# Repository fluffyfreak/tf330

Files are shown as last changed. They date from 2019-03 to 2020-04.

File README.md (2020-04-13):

# tf330

TF330 source files. 

Published under GPL v2. 

TF330 is distributed with absolutely no warranty. If you make a mistake you could blow up your CD32. I take no responsibility for this. 

The TF330 is an 030 accelerator fixed at 50Mhz with 64Mb of SDRAM (128Mb possible), WIFI support (via ESP8266) and is intended to work with CF cards or IDE2SD card type devices. The IDE interface does not work with long cables. It is intended to be CHEAP Because thats pretty much all Amiga users care about. 

**Before you start building :- You can buy these from Supaduper & AlenPPC (AmiBay) completely built for less than it will cost you to buy the parts and the time it will take you if you bill your time at minimum wage.**

If you have poor soldering skills and feel the need to mock me for not using through hole technology please dont bother. I've heard it all before and I will just laugh at you. Through hole sucks. 

Also do not ask me to reroute the board to a different DRC so you can use your local boardhouse. I dont feel like spending 100 hours of my time to save you $10. The DRC on this board is 7-7-7 and any boardhouse that doesnt totally suck can do this. Also it 4 layer and dont ask if i can be made 2 layer. The answer is no. 

If you need help with this the best place to get it is the exxos forum https://www.exxoshost.co.uk/forum/ 

Please do not message me directly. Start a thread. 

I do my best to help people who ask polite questions in public but if you make your inadequecies my problem then you are on your own. 

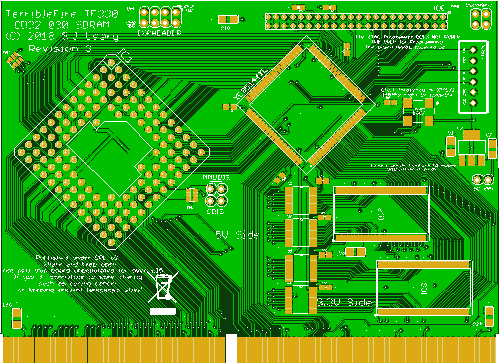
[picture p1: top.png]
Top of board


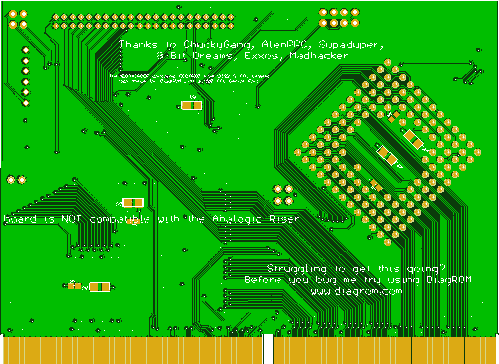
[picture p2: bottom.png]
Bottom of board


I dont care if you think my HDL is not pristine either. It works perfecly fine for what its intended to be. I lothe the wordy VHDL language.. it breaks the most basic principle of coding .. .DONT REPEAT YOURSELF. There is a full regression test suite in my development repo that I have chosen not to share.

The SDRAM Controller is derived from my Archie core and the clock controller code is designed to simulate a PLL with adjustable phase. 

This is not an exercise in German over engineering. Its properly engineered to do an exact task and nothing more. Its a simple repeatable board that works and there are about 500 of them built and working reliably.

I dont like forks because i dont like options. Options mean more testing and more testing = time. So if you fork you are on your own but if you fork and dont give credit I will make it my mission in life to punish you. I will summon the ancient retro spirits of evil like Jack Tramiel and have them haunt you for all time. You have been warned. 

I know this seems a bit hostile but really its just from hard experience of Amiga people. I give this out for free but there are people out there who will take the piss and try to rip off amiga users with clones baring their own name, others will get one of these off ebay for £15 and expect me to invest 100s of hours in helping them get it going. Yet others will try to be smart arses and tell me i've done X, Y or Z wrong and this will never work. If for any reason you decide this board does not measure up to whatever standard YOU think it should be... take a hike. I dont care. 

That said you are free to sell this on your webshop provided you give credit and do not vastly overprice it. However CE marking is your own issue not mine. 

On the other hand if you have an actual firmware bugfix send me a pull request with testing evidence. It will be appreciated greatly. 

For crashes please check that the crash doesnt happen in WinUAE for a CD32 with A1200 IDE and 64MB ZIII Ram before making a bug report. Most of the crashes we have seen over the years are repeatable in that environment. 

This version of the board is cloned from my private repository and is GPL. The version in my private repo is not GPL and anything derived from it is not subject to the GPL v2. It is highly likely that I will eventually release everything in my private repo. I just do so at a pace that keeps the freeloaders and price gougers from making much out of me.

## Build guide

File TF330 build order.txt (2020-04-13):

My order of the build is 

1.    CPLD
2.    Bus switch x4
3.    All 100nf caps x8
4.    SD ram  x2
5.    1K Resistor arrays x2
6.    Volt Reg
7.    10uf caps x3 (Top Board)
8.    22uf  caps x3  (Top board)
9.    Crystal Oscillator 
10.  1uf  x4 (Bottom board)
11.  10uf  x3 (Bottom Board)
12.  030 pga socket (Optional) or 030 CPU
13.  1k  thick film resistors x2 ( by IDE header)
14.  44 pin IDE header socket

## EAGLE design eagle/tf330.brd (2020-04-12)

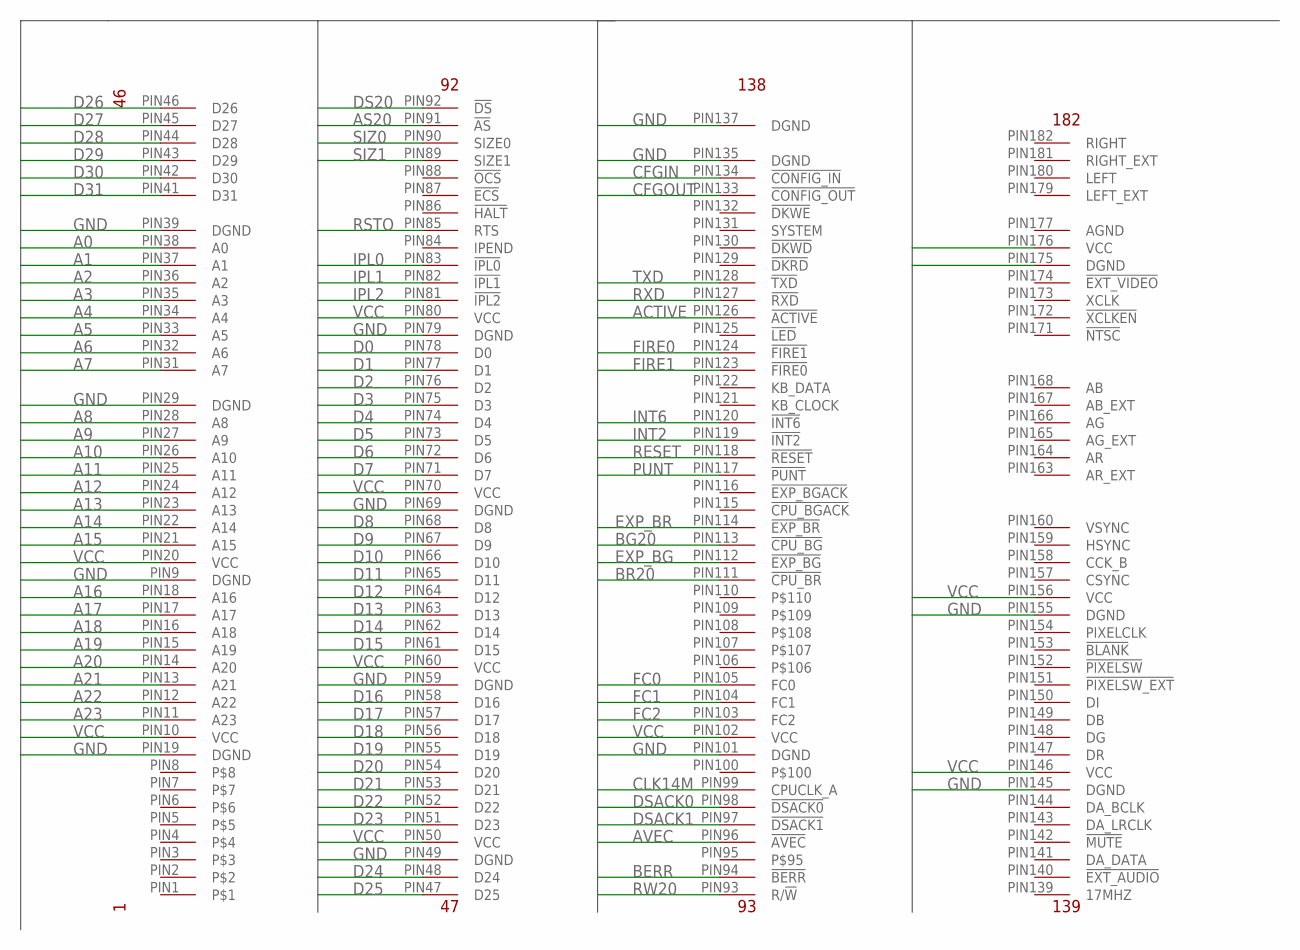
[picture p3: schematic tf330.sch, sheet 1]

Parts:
CONN1: MCA_CONN_182

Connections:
A0: CONN1.PIN38 (A0); also elsewhere on the board
A1: CONN1.PIN37 (A1); also elsewhere on the board
A2: CONN1.PIN36 (A2); also elsewhere on the board
A3: CONN1.PIN35 (A3); also elsewhere on the board
A4: CONN1.PIN34 (A4); also elsewhere on the board
A5: CONN1.PIN33 (A5); also elsewhere on the board
A6: CONN1.PIN32 (A6); also elsewhere on the board
A7: CONN1.PIN31 (A7); also elsewhere on the board
A8: CONN1.PIN28 (A8); also elsewhere on the board
A9: CONN1.PIN27 (A9); also elsewhere on the board
A10: CONN1.PIN26 (A10); also elsewhere on the board
A11: CONN1.PIN25 (A11); also elsewhere on the board
A12: CONN1.PIN24 (A12); also elsewhere on the board
A13: CONN1.PIN23 (A13); also elsewhere on the board
A14: CONN1.PIN22 (A14); also elsewhere on the board
A15: CONN1.PIN21 (A15); also elsewhere on the board
A16: CONN1.PIN18 (A16); also elsewhere on the board
A17: CONN1.PIN17 (A17); also elsewhere on the board
A18: CONN1.PIN16 (A18); also elsewhere on the board
A19: CONN1.PIN15 (A19); also elsewhere on the board
A20: CONN1.PIN14 (A20); also elsewhere on the board
A21: CONN1.PIN13 (A21); also elsewhere on the board
A22: CONN1.PIN12 (A22); also elsewhere on the board
A23: CONN1.PIN11 (A23); also elsewhere on the board
ACTIVE: CONN1.PIN126 (!ACTIVE); also elsewhere on the board
AGND: CONN1.PIN177 (AGND)
AS20: CONN1.PIN91 (!AS); also elsewhere on the board
AVEC: CONN1.PIN96 (!AVEC); also elsewhere on the board
BERR: CONN1.PIN94 (!BERR); also elsewhere on the board
BG20: CONN1.PIN113 (!CPU_BG); also elsewhere on the board
BR20: CONN1.PIN111 (!CPU_BR); also elsewhere on the board
CFGIN: CONN1.PIN134 (!CONFIG_IN)
CFGOUT: CONN1.PIN133 (!CONFIG_OUT)
CLK14M: CONN1.PIN99 (CPUCLK_A); also elsewhere on the board
D0: CONN1.PIN78 (D0); also elsewhere on the board
D1: CONN1.PIN77 (D1); also elsewhere on the board
D2: CONN1.PIN76 (D2); also elsewhere on the board
D3: CONN1.PIN75 (D3); also elsewhere on the board
D4: CONN1.PIN74 (D4); also elsewhere on the board
D5: CONN1.PIN73 (D5); also elsewhere on the board
D6: CONN1.PIN72 (D6); also elsewhere on the board
D7: CONN1.PIN71 (D7); also elsewhere on the board
D8: CONN1.PIN68 (D8); also elsewhere on the board
D9: CONN1.PIN67 (D9); also elsewhere on the board
D10: CONN1.PIN66 (D10); also elsewhere on the board
D11: CONN1.PIN65 (D11); also elsewhere on the board
D12: CONN1.PIN64 (D12); also elsewhere on the board
D13: CONN1.PIN63 (D13); also elsewhere on the board
D14: CONN1.PIN62 (D14); also elsewhere on the board
D15: CONN1.PIN61 (D15); also elsewhere on the board
D16: CONN1.PIN58 (D16); also elsewhere on the board
D17: CONN1.PIN57 (D17); also elsewhere on the board
D18: CONN1.PIN56 (D18); also elsewhere on the board
D19: CONN1.PIN55 (D19); also elsewhere on the board
D20: CONN1.PIN54 (D20); also elsewhere on the board
D21: CONN1.PIN53 (D21); also elsewhere on the board
D22: CONN1.PIN52 (D22); also elsewhere on the board
D23: CONN1.PIN51 (D23); also elsewhere on the board
D24: CONN1.PIN48 (D24); also elsewhere on the board
D25: CONN1.PIN47 (D25); also elsewhere on the board
D26: CONN1.PIN46 (D26); also elsewhere on the board
D27: CONN1.PIN45 (D27); also elsewhere on the board
D28: CONN1.PIN44 (D28); also elsewhere on the board
D29: CONN1.PIN43 (D29); also elsewhere on the board
D30: CONN1.PIN42 (D30); also elsewhere on the board
D31: CONN1.PIN41 (D31); also elsewhere on the board
DS20: CONN1.PIN92 (!DS); also elsewhere on the board
DSACK0: CONN1.PIN98 (!DSACK0); also elsewhere on the board
DSACK1: CONN1.PIN97 (!DSACK1); also elsewhere on the board
EXP_BG: CONN1.PIN112 (!EXP_BG); also elsewhere on the board
EXP_BR: CONN1.PIN114 (!EXP_BR); also elsewhere on the board
FC0: CONN1.PIN105 (FC0); also elsewhere on the board
FC1: CONN1.PIN104 (FC1); also elsewhere on the board
FC2: CONN1.PIN103 (FC2); also elsewhere on the board
FIRE0: CONN1.PIN124 (!FIRE1)
FIRE1: CONN1.PIN123 (!FIRE0)
GND: CONN1.PIN9 (DGND), CONN1.PIN19 (DGND), CONN1.PIN29 (DGND), CONN1.PIN39 (DGND), CONN1.PIN49 (DGND), CONN1.PIN59 (DGND), CONN1.PIN69 (DGND), CONN1.PIN79 (DGND), CONN1.PIN101 (DGND), CONN1.PIN135 (DGND), CONN1.PIN137 (DGND), CONN1.PIN145 (DGND), CONN1.PIN155 (DGND), CONN1.PIN175 (DGND); also elsewhere on the board
INT2: CONN1.PIN119 (!INT2); also elsewhere on the board
INT6: CONN1.PIN120 (!INT6)
IPL0: CONN1.PIN83 (!IPL0); also elsewhere on the board
IPL1: CONN1.PIN82 (!IPL1); also elsewhere on the board
IPL2: CONN1.PIN81 (!IPL2); also elsewhere on the board
PUNT: CONN1.PIN117 (!PUNT); also elsewhere on the board
RESET: CONN1.PIN118 (!RESET); also elsewhere on the board
RSTO: CONN1.PIN85 (RTS); also elsewhere on the board
RW20: CONN1.PIN93 (R/!W); also elsewhere on the board
RXD: CONN1.PIN127 (!RXD); also elsewhere on the board
SIZ0: CONN1.PIN90 (SIZE0); also elsewhere on the board
SIZ1: CONN1.PIN89 (SIZE1); also elsewhere on the board
TXD: CONN1.PIN128 (!TXD); also elsewhere on the board
VCC: CONN1.PIN10 (VCC), CONN1.PIN20 (VCC), CONN1.PIN50 (VCC), CONN1.PIN60 (VCC), CONN1.PIN70 (VCC), CONN1.PIN80 (VCC), CONN1.PIN102 (VCC), CONN1.PIN146 (VCC), CONN1.PIN156 (VCC), CONN1.PIN176 (VCC); also elsewhere on the board

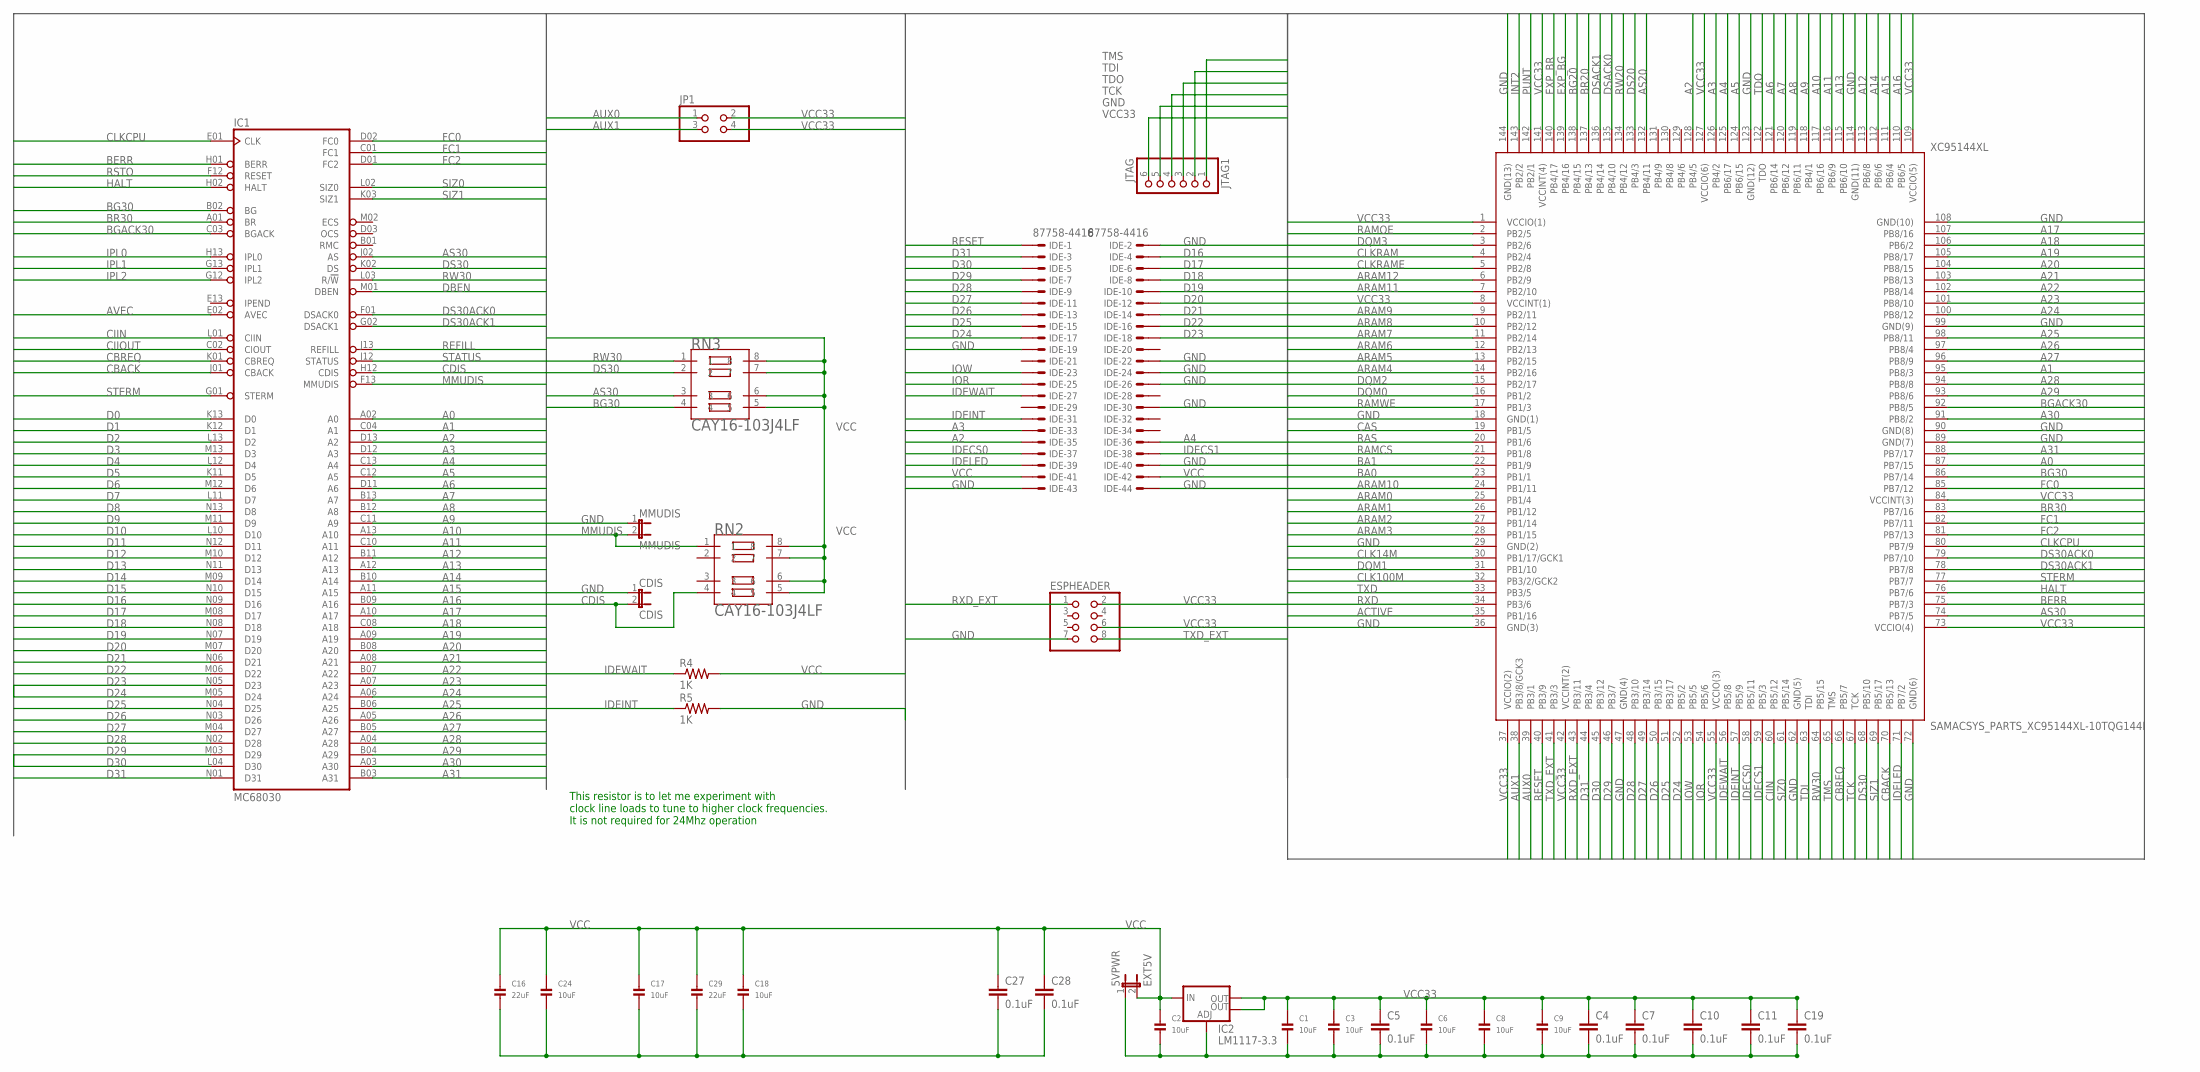
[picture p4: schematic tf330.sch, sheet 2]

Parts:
5VPWR: EXT5V; 1X02
C1, C2, C3, C6, C8, C9, C17, C18, C24: 10uF; 1206
C4, C5, C7, C10, C11, C19, C27, C28: 0.1uF; 0603-CAP
C16, C29: 22uF; 1206
CDIS: CDIS; 1X02
ESPHEADER: PINHD-2X4; 2X04
IC1: MC68030; MPGA128
IC2: LM1117-3.3; SOT223
IDE: 87758-4416
JP1: PINHD-2X2; 2X02
JTAG1: JTAG; 1X06_ROUND
MMUDIS: MMUDIS; 1X02
R4, R5: 1K; 0603
RN2, RN3: CAY16-103J4LF; RESCAXE80P320X160-8N
XC95144XL: SAMACSYS_PARTS_XC95144XL-10TQG144I; SAMACSYS_PARTS_QFP50P2200X2200X160-144N

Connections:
A0: IC1.A02 (A0), XC95144XL.87 (PB7/15); also elsewhere on the board
A1: IC1.C04 (A1), XC95144XL.95 (PB8/3); also elsewhere on the board
A2: IC1.D13 (A2), IDE.35, XC95144XL.128 (PB4/5); also elsewhere on the board
A3: IC1.D12 (A3), IDE.33, XC95144XL.126 (PB4/2); also elsewhere on the board
A4: IC1.C13 (A4), IDE.36, XC95144XL.125 (PB6/17); also elsewhere on the board
A5: IC1.C12 (A5), XC95144XL.124 (PB6/15); also elsewhere on the board
A6: IC1.D11 (A6), XC95144XL.121 (PB6/14); also elsewhere on the board
A7: IC1.B13 (A7), XC95144XL.120 (PB6/12); also elsewhere on the board
A8: IC1.B12 (A8), XC95144XL.119 (PB6/11); also elsewhere on the board
A9: IC1.C11 (A9), XC95144XL.118 (PB4/1); also elsewhere on the board
A10: IC1.A13 (A10), XC95144XL.117 (PB6/16); also elsewhere on the board
A11: IC1.C10 (A11), XC95144XL.116 (PB6/9); also elsewhere on the board
A12: IC1.B11 (A12), XC95144XL.113 (PB6/8); also elsewhere on the board
A13: IC1.A12 (A13), XC95144XL.115 (PB6/10); also elsewhere on the board
A14: IC1.B10 (A14), XC95144XL.112 (PB6/6); also elsewhere on the board
A15: IC1.A11 (A15), XC95144XL.111 (PB6/4); also elsewhere on the board
A16: IC1.B09 (A16), XC95144XL.110 (PB6/5); also elsewhere on the board
A17: IC1.A10 (A17), XC95144XL.107 (PB8/16); also elsewhere on the board
A18: IC1.C08 (A18), XC95144XL.106 (PB6/2); also elsewhere on the board
A19: IC1.A09 (A19), XC95144XL.105 (PB8/17); also elsewhere on the board
A20: IC1.B08 (A20), XC95144XL.104 (PB8/15); also elsewhere on the board
A21: IC1.A08 (A21), XC95144XL.103 (PB8/13); also elsewhere on the board
A22: IC1.B07 (A22), XC95144XL.102 (PB8/14); also elsewhere on the board
A23: IC1.A07 (A23), XC95144XL.101 (PB8/10); also elsewhere on the board
A24: IC1.A06 (A24), XC95144XL.100 (PB8/12)
A25: IC1.B06 (A25), XC95144XL.98 (PB8/11)
A26: IC1.A05 (A26), XC95144XL.97 (PB8/4)
A27: IC1.B05 (A27), XC95144XL.96 (PB8/9)
A28: IC1.A04 (A28), XC95144XL.94 (PB8/8)
A29: IC1.B04 (A29), XC95144XL.93 (PB8/6)
A30: IC1.A03 (A30), XC95144XL.91 (PB8/2)
A31: IC1.B03 (A31), XC95144XL.88 (PB7/17)
ACTIVE: XC95144XL.35 (PB1/16); also elsewhere on the board
ARAM0: XC95144XL.25 (PB1/4); also elsewhere on the board
ARAM1: XC95144XL.26 (PB1/12); also elsewhere on the board
ARAM2: XC95144XL.27 (PB1/14); also elsewhere on the board
ARAM3: XC95144XL.28 (PB1/15); also elsewhere on the board
ARAM4: XC95144XL.14 (PB2/16); also elsewhere on the board
ARAM5: XC95144XL.13 (PB2/15); also elsewhere on the board
ARAM6: XC95144XL.12 (PB2/13); also elsewhere on the board
ARAM7: XC95144XL.11 (PB2/14); also elsewhere on the board
ARAM8: XC95144XL.10 (PB2/12); also elsewhere on the board
ARAM9: XC95144XL.9 (PB2/11); also elsewhere on the board
ARAM10: XC95144XL.24 (PB1/11); also elsewhere on the board
ARAM11: XC95144XL.7 (PB2/10); also elsewhere on the board
ARAM12: XC95144XL.6 (PB2/9); also elsewhere on the board
AS20: XC95144XL.132 (PB4/11); also elsewhere on the board
AS30: IC1.J02 (AS), RN3.3, XC95144XL.74 (PB7/5)
AUX0: JP1.1, XC95144XL.39 (PB3/1)
AUX1: JP1.3, XC95144XL.38 (PB3/8/GCK3)
AVEC: IC1.E02 (AVEC); also elsewhere on the board
BA0: XC95144XL.23 (PB1/1); also elsewhere on the board
BA1: XC95144XL.22 (PB1/9); also elsewhere on the board
BERR: IC1.H01 (BERR), XC95144XL.75 (PB7/3); also elsewhere on the board
BG20: XC95144XL.138 (PB4/15); also elsewhere on the board
BG30: IC1.B02 (BG), RN3.4, XC95144XL.86 (PB7/14)
BGACK30: IC1.C03 (BGACK), XC95144XL.92 (PB8/5)
BR20: XC95144XL.137 (PB4/13); also elsewhere on the board
BR30: IC1.A01 (BR), XC95144XL.83 (PB7/16)
CAS: XC95144XL.19 (PB1/5); also elsewhere on the board
CBACK: IC1.J01 (CBACK), XC95144XL.70 (PB5/13)
CBREQ: IC1.K01 (CBREQ), XC95144XL.66 (PB5/7)
CDIS: CDIS.2, IC1.H12 (CDIS), RN2.4
CIIN: IC1.L01 (CIIN), XC95144XL.60 (PB5/12)
CIIOUT: IC1.C02 (CIOUT)
CLK14M: XC95144XL.30 (PB1/17/GCK1); also elsewhere on the board
CLK100M: XC95144XL.32 (PB3/2/GCK2); also elsewhere on the board
CLKCPU: IC1.E01 (CLK), XC95144XL.80 (PB7/9)
CLKRAM: XC95144XL.4 (PB2/4); also elsewhere on the board
CLKRAME: XC95144XL.5 (PB2/8); also elsewhere on the board
D0: IC1.K13 (D0); also elsewhere on the board
D1: IC1.K12 (D1); also elsewhere on the board
D2: IC1.L13 (D2); also elsewhere on the board
D3: IC1.M13 (D3); also elsewhere on the board
D4: IC1.L12 (D4); also elsewhere on the board
D5: IC1.K11 (D5); also elsewhere on the board
D6: IC1.M12 (D6); also elsewhere on the board
D7: IC1.L11 (D7); also elsewhere on the board
D8: IC1.N13 (D8); also elsewhere on the board
D9: IC1.M11 (D9); also elsewhere on the board
D10: IC1.L10 (D10); also elsewhere on the board
D11: IC1.N12 (D11); also elsewhere on the board
D12: IC1.M10 (D12); also elsewhere on the board
D13: IC1.N11 (D13); also elsewhere on the board
D14: IC1.M09 (D14); also elsewhere on the board
D15: IC1.N10 (D15); also elsewhere on the board
D16: IC1.N09 (D16), IDE.4; also elsewhere on the board
D17: IC1.M08 (D17), IDE.6; also elsewhere on the board
D18: IC1.N08 (D18), IDE.8; also elsewhere on the board
D19: IC1.N07 (D19), IDE.10; also elsewhere on the board
D20: IC1.M07 (D20), IDE.12; also elsewhere on the board
D21: IC1.N06 (D21), IDE.14; also elsewhere on the board
D22: IC1.M06 (D22), IDE.16; also elsewhere on the board
D23: IC1.N05 (D23), IDE.18; also elsewhere on the board
D24: IC1.M05 (D24), IDE.17, XC95144XL.52 (PB5/2); also elsewhere on the board
D25: IC1.N04 (D25), IDE.15, XC95144XL.51 (PB3/17); also elsewhere on the board
D26: IC1.N03 (D26), IDE.13, XC95144XL.50 (PB3/15); also elsewhere on the board
D27: IC1.M04 (D27), IDE.11, XC95144XL.49 (PB3/14); also elsewhere on the board
D28: IC1.N02 (D28), IDE.9, XC95144XL.48 (PB3/10); also elsewhere on the board
D29: IC1.M03 (D29), IDE.7, XC95144XL.46 (PB3/7); also elsewhere on the board
D30: IC1.L04 (D30), IDE.5, XC95144XL.45 (PB3/12); also elsewhere on the board
D31: IC1.N01 (D31), IDE.3, XC95144XL.44 (PB3/4); also elsewhere on the board
DBEN: IC1.M01 (DBEN)
DQM0: XC95144XL.16 (PB1/2); also elsewhere on the board
DQM1: XC95144XL.31 (PB1/10); also elsewhere on the board
DQM2: XC95144XL.15 (PB2/17); also elsewhere on the board
DQM3: XC95144XL.3 (PB2/6); also elsewhere on the board
DS20: XC95144XL.133 (PB4/3); also elsewhere on the board
DS30: IC1.K02 (DS), RN3.2, XC95144XL.68 (PB5/10)
DS30ACK0: IC1.F01 (DSACK0), XC95144XL.79 (PB7/10)
DS30ACK1: IC1.G02 (DSACK1), XC95144XL.78 (PB7/8)
DSACK0: XC95144XL.135 (PB4/10); also elsewhere on the board
DSACK1: XC95144XL.136 (PB4/14); also elsewhere on the board
EXP_BG: XC95144XL.139 (PB4/16); also elsewhere on the board
EXP_BR: XC95144XL.140 (PB4/17); also elsewhere on the board
FC0: IC1.D02 (FC0), XC95144XL.85 (PB7/12); also elsewhere on the board
FC1: IC1.C01 (FC1), XC95144XL.82 (PB7/11); also elsewhere on the board
FC2: IC1.D01 (FC2), XC95144XL.81 (PB7/13); also elsewhere on the board
GND: 5VPWR.1, C1.2, C2.2, C3.2, C4.2, C5.2, C6.2, C7.2, C8.2, C9.2, C10.2, C11.2, C16.2, C17.2, C18.2, C19.2, C24.2, C27.2, C28.2, C29.2, CDIS.1, ESPHEADER.7, IC1.C05 (GND), IC1.C07 (GND), IC1.C09 (GND), IC1.E03 (GND), IC1.E11 (GND), IC1.F03 (GND), IC1.G03 (GND), IC1.G11 (GND), IC1.J03 (GND), IC1.J11 (GND), IC1.L05 (GND), IC1.L07 (GND), IC1.L08 (GND), IC1.L09 (GND), IC2.1 (ADJ), IDE.2, IDE.19, IDE.22, IDE.24, IDE.26, IDE.30, IDE.40, IDE.43, IDE.44, JTAG1.5, MMUDIS.1, R5.2, XC95144XL.18 (GND(1)), XC95144XL.29 (GND(2)), XC95144XL.36 (GND(3)), XC95144XL.47 (GND(4)), XC95144XL.62 (GND(5)), XC95144XL.72 (GND(6)), XC95144XL.89 (GND(7)), XC95144XL.90 (GND(8)), XC95144XL.99 (GND(9)), XC95144XL.108 (GND(10)), XC95144XL.114 (GND(11)), XC95144XL.123 (GND(12)), XC95144XL.144 (GND(13)); also elsewhere on the board
HALT: IC1.H02 (HALT), XC95144XL.76 (PB7/6)
IDECS0: IDE.37, XC95144XL.58 (PB5/11)
IDECS1: IDE.38, XC95144XL.59 (PB5/3)
IDEINT: IDE.31, R5.1, XC95144XL.57 (PB5/9)
IDELED: IDE.39, XC95144XL.71 (PB7/2)
IDEWAIT: IDE.27, R4.1, XC95144XL.56 (PB5/8)
INT2: XC95144XL.143 (PB2/2); also elsewhere on the board
IOR: IDE.25, XC95144XL.54 (PB5/6)
IOW: IDE.23, XC95144XL.53 (PB5/5)
IPL0: IC1.H13 (IPL0); also elsewhere on the board
IPL1: IC1.G13 (IPL1); also elsewhere on the board
IPL2: IC1.G12 (IPL2); also elsewhere on the board
MMUDIS: IC1.F13 (MMUDIS), MMUDIS.2, RN2.1
PUNT: XC95144XL.142 (PB2/1); also elsewhere on the board
RAMCS: XC95144XL.21 (PB1/8); also elsewhere on the board
RAMOE: XC95144XL.2 (PB2/5); also elsewhere on the board
RAMWE: XC95144XL.17 (PB1/3); also elsewhere on the board
RAS: XC95144XL.20 (PB1/6); also elsewhere on the board
REFILL: IC1.J13 (REFILL)
RESET: IDE.1, XC95144XL.40 (PB3/9); also elsewhere on the board
RSTO: IC1.F12 (RESET); also elsewhere on the board
RW20: XC95144XL.134 (PB4/12); also elsewhere on the board
RW30: IC1.L03 (R/!W), RN3.1, XC95144XL.64 (PB5/15)
RXD: XC95144XL.34 (PB3/6); also elsewhere on the board
RXD_EXT: ESPHEADER.1, XC95144XL.43 (PB3/11)
SIZ0: IC1.L02 (SIZ0), XC95144XL.61 (PB5/14); also elsewhere on the board
SIZ1: IC1.K03 (SIZ1), XC95144XL.69 (PB5/17); also elsewhere on the board
STATUS: IC1.J12 (STATUS)
STERM: IC1.G01 (STERM), XC95144XL.77 (PB7/7)
TCK: JTAG1.4, XC95144XL.67 (TCK)
TDI: JTAG1.2, XC95144XL.63 (TDI)
TDO: JTAG1.3, XC95144XL.122 (TDO)
TMS: JTAG1.1, XC95144XL.65 (TMS)
TXD: XC95144XL.33 (PB3/5); also elsewhere on the board
TXD_EXT: ESPHEADER.8, XC95144XL.41 (PB3/3)
VCC: 5VPWR.2, C2.1, C16.1, C17.1, C18.1, C24.1, C27.1, C28.1, C29.1, IC1.C06 (VCC), IC1.D04 (VCC), IC1.D10 (VCC), IC1.F02 (VCC), IC1.F11 (VCC), IC1.H03 (VCC), IC1.H11 (VCC), IC1.K04 (VCC), IC1.K10 (VCC), IC1.L06 (VCC), IC2.3 (IN), IDE.41, IDE.42, R4.2, RN2.5, RN2.6, RN2.7, RN2.8, RN3.5, RN3.6, RN3.7, RN3.8; also elsewhere on the board
VCC33: C1.1, C3.1, C4.1, C5.1, C6.1, C7.1, C8.1, C9.1, C10.1, C11.1, C19.1, ESPHEADER.2, ESPHEADER.6, IC2.2 (OUT), IC2.4 (OUT), JP1.2, JP1.4, JTAG1.6, XC95144XL.1 (VCCIO(1)), XC95144XL.8 (VCCINT(1)), XC95144XL.37 (VCCIO(2)), XC95144XL.42 (VCCINT(2)), XC95144XL.55 (VCCIO(3)), XC95144XL.73 (VCCIO(4)), XC95144XL.84 (VCCINT(3)), XC95144XL.109 (VCCIO(5)), XC95144XL.127 (VCCIO(6)), XC95144XL.141 (VCCINT(4)); also elsewhere on the board

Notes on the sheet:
This resistor is to let me experiment with clock line loads to tune to higher clock frequencies. It is not required for 24Mhz operation

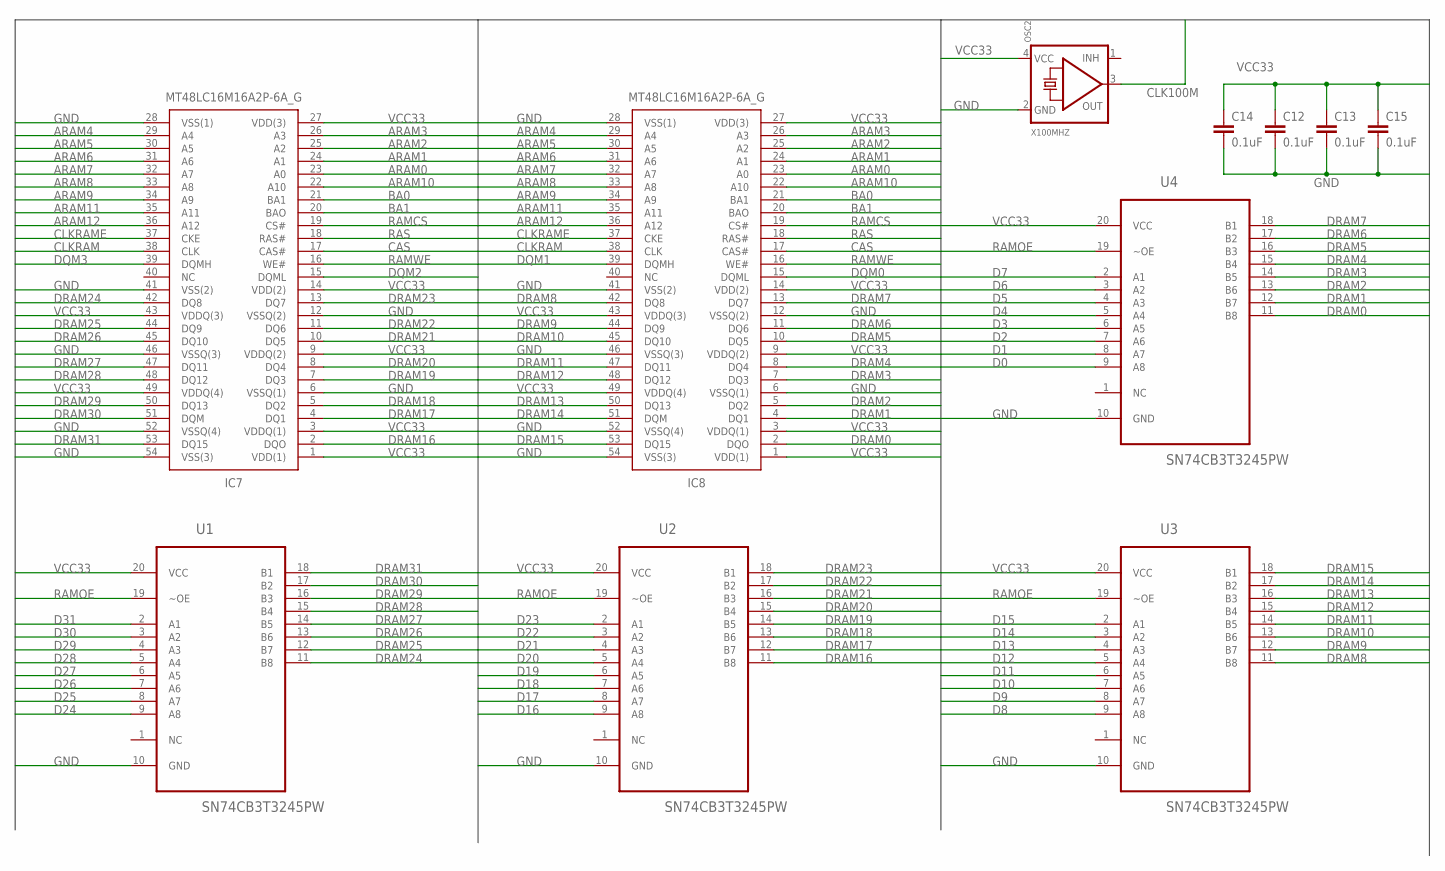
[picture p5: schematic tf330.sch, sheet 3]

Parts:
C12, C13, C14, C15: 0.1uF; 0603-CAP
IC7, IC8: MT48LC16M16A2P-6A_G; SOP80P1176X120-54N
OSC2: X100MHZ; OSC_7X5MM
U1, U2, U3, U4: SN74CB3T3245PW; SOP65P640X120-20N

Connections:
ARAM0: IC7.23 (A0), IC8.23 (A0); also elsewhere on the board
ARAM1: IC7.24 (A1), IC8.24 (A1); also elsewhere on the board
ARAM2: IC7.25 (A2), IC8.25 (A2); also elsewhere on the board
ARAM3: IC7.26 (A3), IC8.26 (A3); also elsewhere on the board
ARAM4: IC7.29 (A4), IC8.29 (A4); also elsewhere on the board
ARAM5: IC7.30 (A5), IC8.30 (A5); also elsewhere on the board
ARAM6: IC7.31 (A6), IC8.31 (A6); also elsewhere on the board
ARAM7: IC7.32 (A7), IC8.32 (A7); also elsewhere on the board
ARAM8: IC7.33 (A8), IC8.33 (A8); also elsewhere on the board
ARAM9: IC7.34 (A9), IC8.34 (A9); also elsewhere on the board
ARAM10: IC7.22 (A10), IC8.22 (A10); also elsewhere on the board
ARAM11: IC7.35 (A11), IC8.35 (A11); also elsewhere on the board
ARAM12: IC7.36 (A12), IC8.36 (A12); also elsewhere on the board
BA0: IC7.21 (BA1), IC8.21 (BA1); also elsewhere on the board
BA1: IC7.20 (BAO), IC8.20 (BAO); also elsewhere on the board
CAS: IC7.17 (CAS#), IC8.17 (CAS#); also elsewhere on the board
CLK100M: OSC2.3 (OUT); also elsewhere on the board
CLKRAM: IC7.38 (CLK), IC8.38 (CLK); also elsewhere on the board
CLKRAME: IC7.37 (CKE), IC8.37 (CKE); also elsewhere on the board
D0: U4.9 (A8); also elsewhere on the board
D1: U4.8 (A7); also elsewhere on the board
D2: U4.7 (A6); also elsewhere on the board
D3: U4.6 (A5); also elsewhere on the board
D4: U4.5 (A4); also elsewhere on the board
D5: U4.4 (A3); also elsewhere on the board
D6: U4.3 (A2); also elsewhere on the board
D7: U4.2 (A1); also elsewhere on the board
D8: U3.9 (A8); also elsewhere on the board
D9: U3.8 (A7); also elsewhere on the board
D10: U3.7 (A6); also elsewhere on the board
D11: U3.6 (A5); also elsewhere on the board
D12: U3.5 (A4); also elsewhere on the board
D13: U3.4 (A3); also elsewhere on the board
D14: U3.3 (A2); also elsewhere on the board
D15: U3.2 (A1); also elsewhere on the board
D16: U2.9 (A8); also elsewhere on the board
D17: U2.8 (A7); also elsewhere on the board
D18: U2.7 (A6); also elsewhere on the board
D19: U2.6 (A5); also elsewhere on the board
D20: U2.5 (A4); also elsewhere on the board
D21: U2.4 (A3); also elsewhere on the board
D22: U2.3 (A2); also elsewhere on the board
D23: U2.2 (A1); also elsewhere on the board
D24: U1.9 (A8); also elsewhere on the board
D25: U1.8 (A7); also elsewhere on the board
D26: U1.7 (A6); also elsewhere on the board
D27: U1.6 (A5); also elsewhere on the board
D28: U1.5 (A4); also elsewhere on the board
D29: U1.4 (A3); also elsewhere on the board
D30: U1.3 (A2); also elsewhere on the board
D31: U1.2 (A1); also elsewhere on the board
DQM0: IC8.15 (DQML); also elsewhere on the board
DQM1: IC8.39 (DQMH); also elsewhere on the board
DQM2: IC7.15 (DQML); also elsewhere on the board
DQM3: IC7.39 (DQMH); also elsewhere on the board
DRAM0: IC8.2 (DQO), U4.11 (B8)
DRAM1: IC8.4 (DQ1), U4.12 (B7)
DRAM2: IC8.5 (DQ2), U4.13 (B6)
DRAM3: IC8.7 (DQ3), U4.14 (B5)
DRAM4: IC8.8 (DQ4), U4.15 (B4)
DRAM5: IC8.10 (DQ5), U4.16 (B3)
DRAM6: IC8.11 (DQ6), U4.17 (B2)
DRAM7: IC8.13 (DQ7), U4.18 (B1)
DRAM8: IC8.42 (DQ8), U3.11 (B8)
DRAM9: IC8.44 (DQ9), U3.12 (B7)
DRAM10: IC8.45 (DQ10), U3.13 (B6)
DRAM11: IC8.47 (DQ11), U3.14 (B5)
DRAM12: IC8.48 (DQ12), U3.15 (B4)
DRAM13: IC8.50 (DQ13), U3.16 (B3)
DRAM14: IC8.51 (DQM), U3.17 (B2)
DRAM15: IC8.53 (DQ15), U3.18 (B1)
DRAM16: IC7.2 (DQO), U2.11 (B8)
DRAM17: IC7.4 (DQ1), U2.12 (B7)
DRAM18: IC7.5 (DQ2), U2.13 (B6)
DRAM19: IC7.7 (DQ3), U2.14 (B5)
DRAM20: IC7.8 (DQ4), U2.15 (B4)
DRAM21: IC7.10 (DQ5), U2.16 (B3)
DRAM22: IC7.11 (DQ6), U2.17 (B2)
DRAM23: IC7.13 (DQ7), U2.18 (B1)
DRAM24: IC7.42 (DQ8), U1.11 (B8)
DRAM25: IC7.44 (DQ9), U1.12 (B7)
DRAM26: IC7.45 (DQ10), U1.13 (B6)
DRAM27: IC7.47 (DQ11), U1.14 (B5)
DRAM28: IC7.48 (DQ12), U1.15 (B4)
DRAM29: IC7.50 (DQ13), U1.16 (B3)
DRAM30: IC7.51 (DQM), U1.17 (B2)
DRAM31: IC7.53 (DQ15), U1.18 (B1)
GND: C12.2, C13.2, C14.2, C15.2, IC7.6 (VSSQ(1)), IC7.12 (VSSQ(2)), IC7.28 (VSS(1)), IC7.41 (VSS(2)), IC7.46 (VSSQ(3)), IC7.52 (VSSQ(4)), IC7.54 (VSS(3)), IC8.6 (VSSQ(1)), IC8.12 (VSSQ(2)), IC8.28 (VSS(1)), IC8.41 (VSS(2)), IC8.46 (VSSQ(3)), IC8.52 (VSSQ(4)), IC8.54 (VSS(3)), OSC2.2 (GND), U1.10 (GND), U2.10 (GND), U3.10 (GND), U4.10 (GND); also elsewhere on the board
RAMCS: IC7.19 (CS#), IC8.19 (CS#); also elsewhere on the board
RAMOE: U1.19 (~OE), U2.19 (~OE), U3.19 (~OE), U4.19 (~OE); also elsewhere on the board
RAMWE: IC7.16 (WE#), IC8.16 (WE#); also elsewhere on the board
RAS: IC7.18 (RAS#), IC8.18 (RAS#); also elsewhere on the board
VCC33: C12.1, C13.1, C14.1, C15.1, IC7.1 (VDD(1)), IC7.3 (VDDQ(1)), IC7.9 (VDDQ(2)), IC7.14 (VDD(2)), IC7.27 (VDD(3)), IC7.43 (VDDQ(3)), IC7.49 (VDDQ(4)), IC8.1 (VDD(1)), IC8.3 (VDDQ(1)), IC8.9 (VDDQ(2)), IC8.14 (VDD(2)), IC8.27 (VDD(3)), IC8.43 (VDDQ(3)), IC8.49 (VDDQ(4)), OSC2.4 (VCC), U1.20 (VCC), U2.20 (VCC), U3.20 (VCC), U4.20 (VCC); also elsewhere on the board

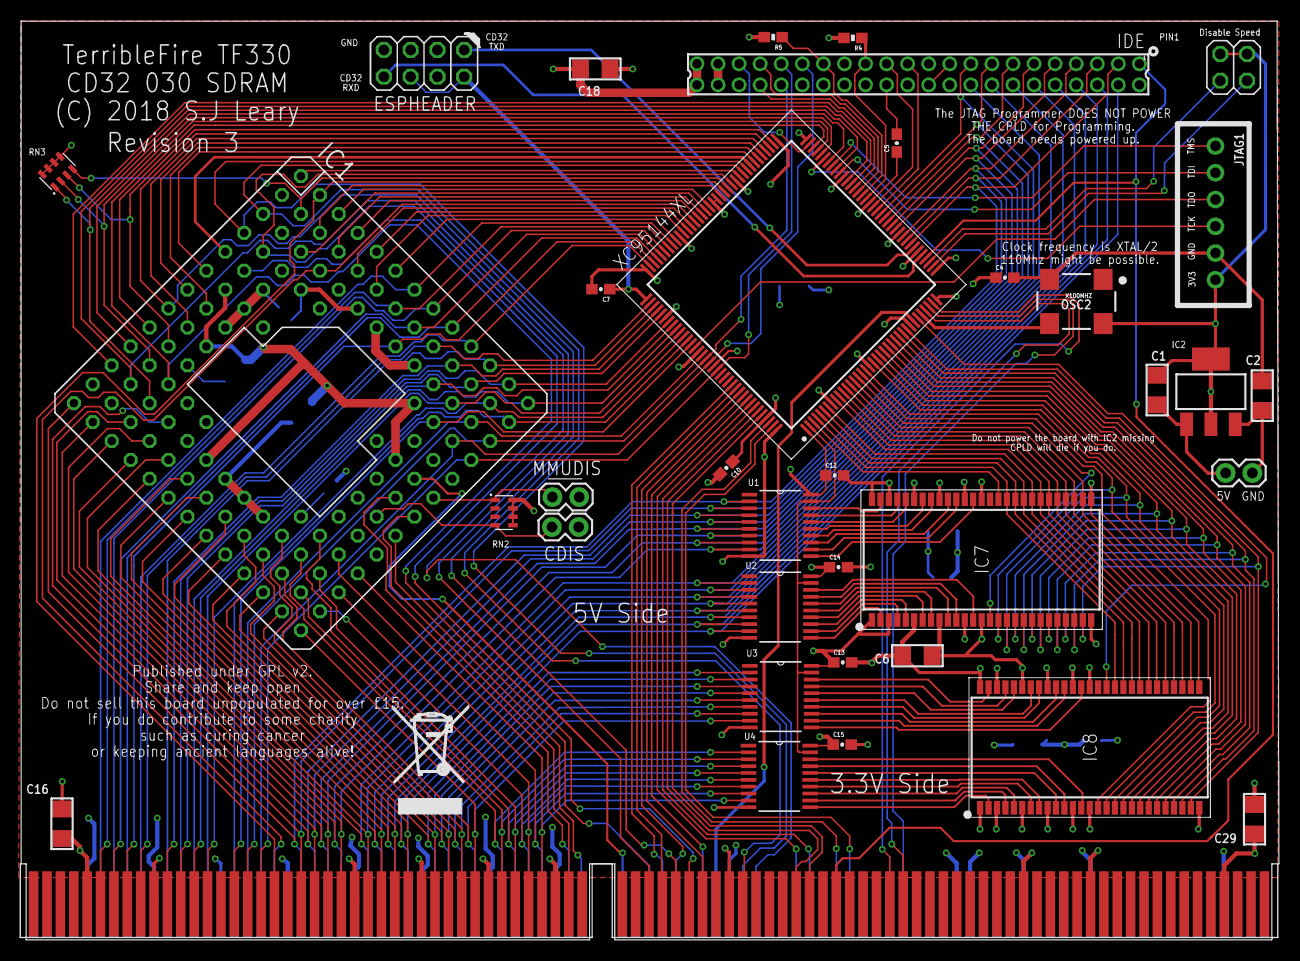
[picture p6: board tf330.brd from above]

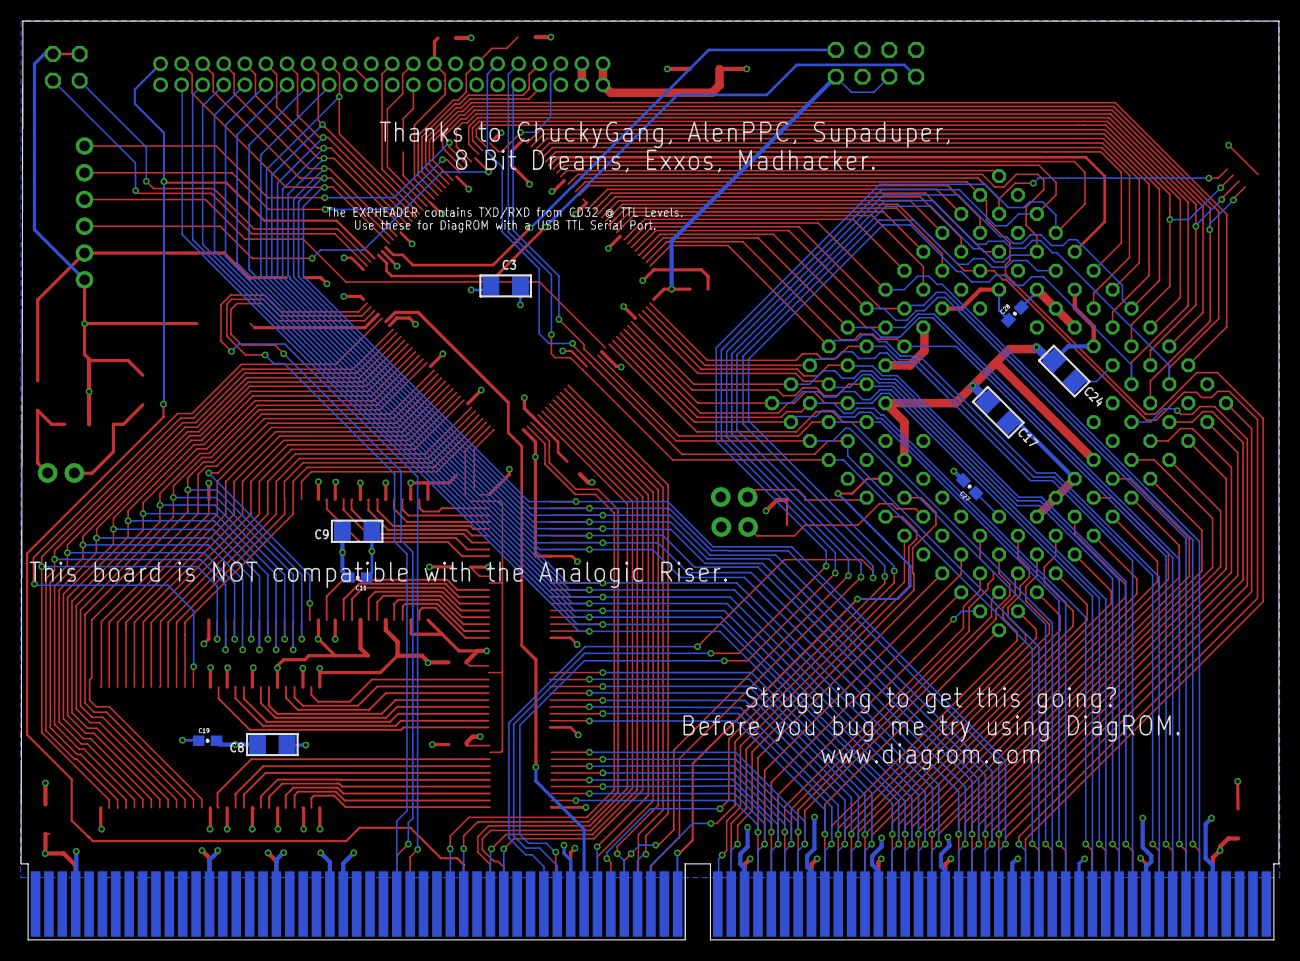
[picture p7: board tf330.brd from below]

Board: 4 copper layers, 119.4 x 87.2 mm, 45 parts (9 on the bottom side), 184 nets.

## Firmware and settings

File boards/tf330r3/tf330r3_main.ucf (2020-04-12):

# Copyright (C) 2016-2017, Stephen J. Leary
# All rights reserved.
#
# This file is part of TF530 (Terrible Fire 030 Accelerator)
#
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
#Clocks
NET "CLK100M"		LOC="32";
NET "CLK100M" BUFG=CLK;
NET "CLK100M" TNM_NET = "CLK100M"; # gives the net clk a group name as CLK100M

NET "CLK14M"		LOC="30";
NET "CLK14M" BUFG=CLK;
NET "CLK14M" TNM_NET = "CLK14M"; # gives the net clk a group name as CLK14M

NET "A<0>"      LOC="87";
NET "A<1>"      LOC="95";
NET "A<2>"      LOC="128";
NET "A<3>"      LOC="126";
NET "A<4>"      LOC="125";
NET "A<5>"      LOC="124";
NET "A<6>"      LOC="121";
NET "A<7>"      LOC="120";
NET "A<8>"      LOC="119";
NET "A<9>"      LOC="118";
NET "A<10>"      LOC="117";
NET "A<11>"      LOC="116";
NET "A<12>"      LOC="113";
NET "A<13>"      LOC="115";
NET "A<14>"      LOC="112";
NET "A<15>"      LOC="111";
NET "A<16>"      LOC="110";
NET "A<17>"      LOC="107";
NET "A<18>"      LOC="106";
NET "A<19>"      LOC="105";
NET "A<20>"      LOC="104";
NET "A<21>"      LOC="103";
NET "A<22>"      LOC="102";
NET "A<23>"      LOC="101";
NET "A<24>"      LOC="100";
NET "A<25>"      LOC="98";
NET "A<26>"      LOC="97";
NET "A<27>"      LOC="96";
NET "A<28>"      LOC="94";
NET "A<29>"      LOC="93";
NET "A<30>"      LOC="91";
NET "A<31>"      LOC="88";
NET "ACTIVE"      LOC="35";
NET "ARAM<0>"      LOC="25";
NET "ARAM<1>"      LOC="26";
NET "ARAM<2>"      LOC="27";
NET "ARAM<3>"      LOC="28";
NET "ARAM<4>"      LOC="14";
NET "ARAM<5>"      LOC="13";
NET "ARAM<6>"      LOC="12";
NET "ARAM<7>"      LOC="11";
NET "ARAM<8>"      LOC="10";
NET "ARAM<9>"      LOC="9";
NET "ARAM<10>"      LOC="24";
NET "ARAM<11>"      LOC="7";
NET "ARAM<12>"      LOC="6";
NET "AS20"      LOC="132";
NET "AS30"      LOC="74";
NET "DISABLE"      LOC="39";
NET AUXGND      LOC="38";
#NET "AUX<2>"      LOC="40";
NET "BA<0>"      LOC="23";
NET "BA<1>"      LOC="22";
NET "BERR"      LOC="75";
NET "BG20"      LOC="138";
NET "BG30"      LOC="86";
NET "BGACK30"      LOC="92";
NET "BR20"      LOC="137";
NET "BR30"      LOC="83";
NET "CAS"      LOC="19";
NET "CBACK"      LOC="70";
NET "CBREQ"      LOC="66";
NET "CIIN"      LOC="60";
NET "CLKCPU"      LOC="80";
NET "CLKRAM"      LOC="4";
NET "CLKRAME"      LOC="5";
NET "D<24>"      LOC="52";
NET "D<25>"      LOC="51";
NET "D<26>"      LOC="50";
NET "D<27>"      LOC="49";
NET "D<28>"      LOC="48";
NET "D<29>"      LOC="46";
NET "D<30>"      LOC="45";
NET "D<31>"      LOC="44";
NET "DQM<0>"      LOC="16";
NET "DQM<1>"      LOC="31";
NET "DQM<2>"      LOC="15";
NET "DQM<3>"      LOC="3";
NET "DS20"      LOC="133";
NET "DS30"      LOC="68";
NET "DS30ACK<0>"      LOC="79";
NET "DS30ACK<1>"      LOC="78";
NET "DSACK<0>"      LOC="135";
NET "DSACK<1>"      LOC="136";
NET "EXP_BG"      LOC="139";
NET "EXP_BR"      LOC="140";
NET "FC<0>"      LOC="85";
NET "FC<1>"      LOC="82";
NET "FC<2>"      LOC="81";
NET "HALT"      LOC="76";
NET "IDECS<0>"      LOC="58";
NET "IDECS<1>"      LOC="59";
NET "IDEINT"      LOC="57";
NET "IDELED"      LOC="71";
NET "IDEWAIT"      LOC="56";
NET "INT2"      LOC="143";
NET "IOR"      LOC="54";
NET "IOW"      LOC="53";
NET "PUNT"      LOC="142";
NET "RAMCS"      LOC="21";
NET "RAMOE"      LOC="2";
NET "RAMWE"      LOC="17";
NET "RAS"      LOC="20";
NET "RESET"      LOC="40";
NET "RW20"      LOC="134";
NET "RW30"      LOC="64";
NET "RXD"      LOC="34";
NET "RXD_EXT"      LOC="43";
NET "SIZ<0>"      LOC="61";
NET "SIZ<1>"      LOC="69";
NET "STERM"      LOC="77";
NET "TXD"      LOC="33";
NET "TXD_EXT"      LOC="41";

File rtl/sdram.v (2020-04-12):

`timescale 1ns / 1ps
/*
    Copyright (C) 2019, Stephen J. Leary
    All rights reserved.
    
    This file is part of  TF330 (Terrible Fire 030 Accelerator).

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
    You should have received a copy of the GNU General Public License
    along with TF330. If not, see <http://www.gnu.org/licenses/>.
*/


module sdram(

           input        RESET,
           input        CLKCPU,
           input        CLK, 
           input        ACCESS,

           input [31:0] A,
           input [1:0]  SIZ,

           input        AS30,
           input        RW30,
           input        DS30,

           // cache and burst control
           output       CBACK,
           output       CIIN,
           input        CBREQ,
           output       STERM, 
           output       WAIT,

           // ram chip control
           //  SDRAM Control
           output			CLKRAME,
           output [12:0]    ARAM,
           output [1:0] 	BA,
           output			CAS,
           output [3:0] 	DQM,
           output			RAMWE,
           output			RAS,
           output			RAMCS,
           output			RAMOE,
           output [(12*8)-1:0]     COMMANDNAME


    );

`include "sdram_defines.v"

wire        ready;

wire        init_clke;
wire [3:0]  init_command;
wire [12:0] init_address;

reg STERM_D;
reg WAITSTATE;

reg [3:0]   command = CMD_NOP;
reg [3:0]   cycle   = 'd0;
reg [1:0]   bank    = 0;
reg [12:0]  address = 0;

wire refresh;

assign COMMANDNAME = cmd_name(ready ? init_command : command);

localparam MODE = { 3'b000, NO_WRITE_BURST, OP_MODE, CAS_LATENCY, ACCESS_TYPE, BURST_LENGTH};

sdram_init #
(
	.MODE(MODE)
)
INIT(

    .CLK    ( CLK           ),
    .CLKE   ( init_clke     ),
    .RESET  ( RESET         ),

    .CMD    ( init_command  ),
    .ARAM   ( init_address  ),
    .READY  ( ready         ),
    .REFRESH( refresh       )

);

reg refresh_d;
reg refresh_req;

localparam CYCLE_ACCESS = 'b0;
localparam CYCLE_REFRESH = 'b1;

localparam CYCLE_REFRESH_AUTOREFRESH1 = 5'b10011;
localparam CYCLE_REFRESH_AUTOREFRESH2 = 5'b10111;
localparam CYCLE_REFRESH_COMPLETE= 5'b11111;
localparam CYCLE_ACCESS_START = 5'b00001;
localparam CYCLE_ACCESS_RW = 5'b00010;
localparam CYCLE_ACCESS_COMPLETE = 5'b00011;
localparam CYCLE_ACCESS_BW1 = 5'b00100;
localparam CYCLE_ACCESS_BW2 = 5'b00101;

reg BURSTING = 1'b0;
reg [1:0] BCOUNT = 2'b11;

// a read cycle at a tag aligned address. 
wire CAN_BURST = ({A[3:2]} != 2'b00) | CBREQ | ACCESS | ~RW30;
wire [1:0] RAMA = BURSTING ? {A[3:2]} : BCOUNT;

wire BURST_ENDING = (BCOUNT == 2'b11) | BURSTING;

reg cycle_type;
reg can_start;

reg WAIT_BLOCK = 1'b1;
reg [3:0] DQM_D;

always @(posedge CLK or negedge RESET) begin 

    if (RESET == 1'b0) begin 

        command     <= CMD_NOP;
        address     <= 'd0;
        bank        <= 'd0;
        refresh_req <= 'b1;
        refresh_d   <= 'b0;
        cycle       <= 'd0;
        cycle_type  <= 'd0;

    end else begin 

        command <= CMD_NOP;

        DQM_D[3] <= ACCESS | ~RW30 & (A[1] | A[0]);
        DQM_D[2] <= ACCESS | ~RW30 & ((~SIZ[1] & SIZ[0] & ~A[0]) | A[1]);
        DQM_D[1] <= ACCESS | ~RW30 & ((SIZ[1] & ~SIZ[0] & ~A[1] & ~A[0]) | (~SIZ[1] & SIZ[0] & ~A[1]) |(A[1] & A[0]));
        DQM_D[0] <= ACCESS | ~RW30 & ((~SIZ[1] & SIZ[0] & ~A[1] ) | (~SIZ[1] & SIZ[0] & ~A[0] ) | (SIZ[1] & ~A[1] & ~A[0] ) | (SIZ[1] & ~SIZ[0] & ~A[1]));

        if (AS30 == 1'b1) begin 

            can_start <= 1'b0;

        end

        // is a refresh required?
        refresh_d <= refresh;
        if ({refresh, refresh_d} == 2'b01) refresh_req <= 1'b0;

        if (cycle == 'd0) begin 
            
            WAIT_BLOCK <= 1'b1;
            BURSTING <= 1'b1;
            BCOUNT <= 'd0;
            
            if ((ready | can_start) == 1'b0) begin 

                address <= { A[23:11] };

                if (refresh_req == 1'b0) begin 

                    cycle_type <= CYCLE_REFRESH;
                    cycle[0] <= 'd1;

                end else if ((ACCESS | AS30) == 1'b0) begin 
                    
                    BURSTING <= CAN_BURST;
                    cycle_type <= CYCLE_ACCESS;
                    can_start <= 1'b1; 
                    cycle[0] <= 'd1;

                    address <= { A[23:11] };
                    command <= CMD_ACTIVE;
                    bank <= A[25:24];
                
                end

            end

        end else begin 

            // process the in progress cycle.
            cycle <= cycle + 'd1;

            casez  ({cycle_type, cycle}) 

                CYCLE_REFRESH_AUTOREFRESH1: begin 
                    //command			<= CMD_PRECHARGE;
					address[10] 	<= 1'b1;      // precharge all banks
                end

                CYCLE_REFRESH_AUTOREFRESH2: begin 
                    command			<= CMD_AUTO_REFRESH;
                end
                
                CYCLE_ACCESS_RW: begin 
                    
                    address[8:0] <= { A[10:4], RAMA };
                    address[12:9] <= RW30 ?  4'b0000 : 4'b0010;
                    command <= RW30 ? CMD_READ : CMD_WRITE;
                    WAIT_BLOCK <= 'b0;
                    end                    

                CYCLE_ACCESS_COMPLETE: begin 
                    
                    address[8:0] <= { A[10:4], RAMA };
                    address[12:9] <= BURST_ENDING ? 4'b0010 : 4'b0000; // AUTO PRECHARGE ?
                    command <= RW30 ? CMD_READ : CMD_NOP;
                    BCOUNT <= BCOUNT + 'd1;
                    cycle <= BURST_ENDING ? 'd0 : CYCLE_ACCESS_BW1[3:0];

                end

                CYCLE_REFRESH_COMPLETE: begin 
                    refresh_req <= 1'b1;
                    cycle <= 'd0;
                end

                CYCLE_ACCESS_BW1: begin 
                    WAIT_BLOCK <= 'b1;
                end

                CYCLE_ACCESS_BW2: begin 
                    cycle <= CYCLE_ACCESS_RW[3:0];
                end 

                default: begin 
                    command <= CMD_NOP;
                end 

            endcase

        end

    end

end

always @(posedge CLKCPU or posedge AS30) begin	

    if (AS30 == 1'b1) begin 
        
        WAITSTATE <= 1'b1;
        STERM_D <= 1'b1;

    end else begin 

        WAITSTATE <= ACCESS | DS30 | WAIT_BLOCK;
        STERM_D <= WAIT_BLOCK;

    end
end

assign RAMOE = ACCESS;
assign DQM = DQM_D;

assign CIIN = ~ACCESS;
assign CBACK = BURSTING | CBREQ;

assign RAMCS    = 1'b0;
assign RAS      = ready ? init_command[2] : command[2];
assign CAS      = ready ? init_command[1] : command[1];
assign RAMWE    = ready ? init_command[0] : command[0];

assign ARAM     = ready ? init_address : address;
assign BA       = ready ? 2'b00 : bank;
assign CLKRAME  = 1'b1;

assign STERM = STERM_D;

endmodule

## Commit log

2019-03-28 adding the obv files
    [tf330_obv.brd]
2020-04-12 First public version of tf330
    [tf330.brd, tf330.sch]
2020-04-13 Added JLC PCB Gerbers
2020-04-13 Board images
2020-04-13 Added bom files

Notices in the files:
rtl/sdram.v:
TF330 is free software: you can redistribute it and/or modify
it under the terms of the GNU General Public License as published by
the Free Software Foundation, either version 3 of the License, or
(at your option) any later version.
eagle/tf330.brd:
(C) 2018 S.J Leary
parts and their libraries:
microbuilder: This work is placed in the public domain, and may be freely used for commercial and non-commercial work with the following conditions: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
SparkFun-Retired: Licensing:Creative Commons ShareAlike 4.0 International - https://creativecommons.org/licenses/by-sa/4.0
